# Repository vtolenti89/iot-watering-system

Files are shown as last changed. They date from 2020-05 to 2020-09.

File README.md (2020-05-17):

# IoT Watering System
Automated low power watering system 

# Overview
This project aims to automate a watering system for a small garden.
Due to the lack of an outside spigot / outdoor faucet, a large 
reservoir and an intermediate container were used to store the water,
which then was pumped to the plants at a regular interval using
an arduino controlled pump.  

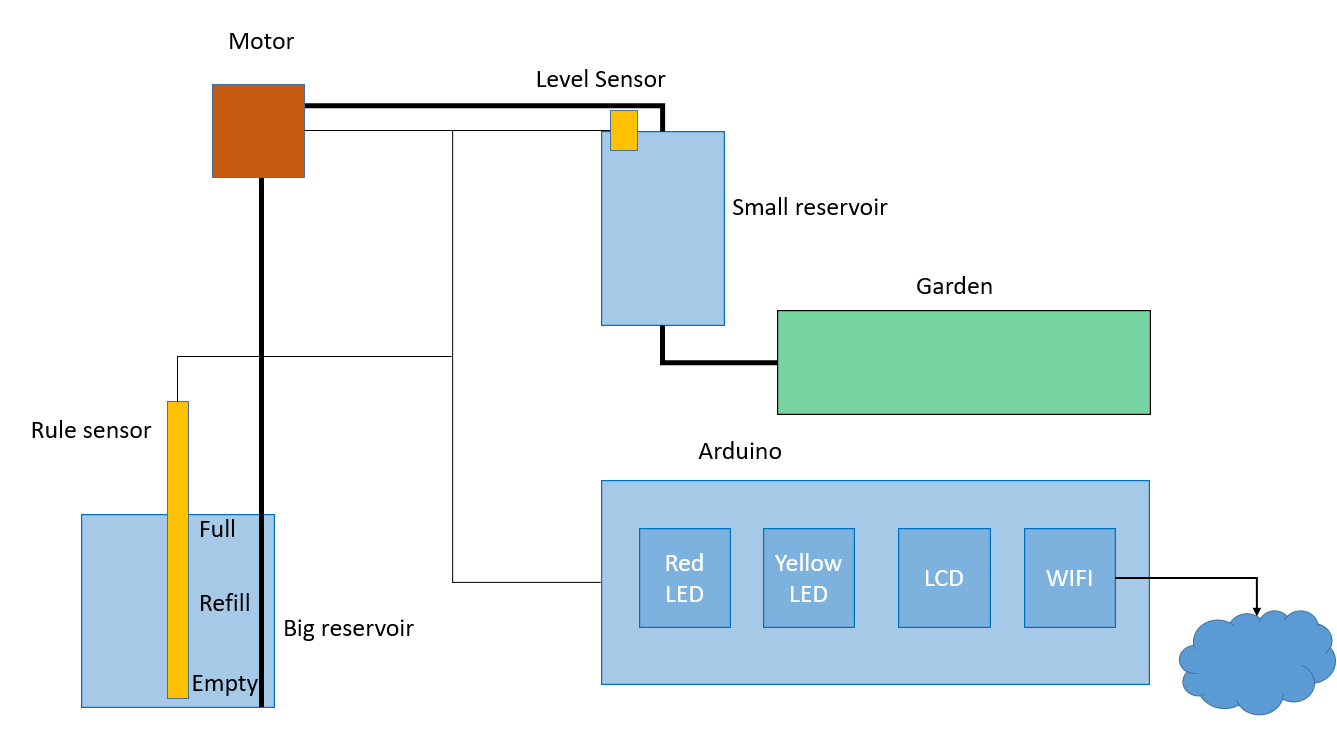
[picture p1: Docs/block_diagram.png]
Block diagram


# Description
The larger reservoir ensures that there is enough water for a resonable time.
Pumping the water to an intermediate container, alleviates the requirement
for the water pump, since it does not have to force the water through the end
nozzles. In this arrangement, gravity will ensure that the water is evenly 
distributed through all of them.
A homemade ruler sensor is used to measure the water level of the main tank,
while the smaller container's sensor prevents any overflow. 

# TODO
* Implement the display
* Implement again wifi with low power option

# History
* Implement a second code version, where the wifi is disabled and the power consumption is drastically
reduced by hardware modification and use of deep sleep routines
* Implement first version with wifi

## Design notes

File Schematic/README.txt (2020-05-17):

Several features of the current schematic were removed / disabled in order to improve the power consumption
Changes implemented in the arduino:

1. LDO removed, thus external supply voltage other than the USB is not possible
2. Apart from the built-in LED, all other LEDs were removed.
3. Supply voltage of the CH340 was removed

Changes implemented in the peripheral circuitry:

1. ESP8266 WIfi module removed
2. Water level meter disabled

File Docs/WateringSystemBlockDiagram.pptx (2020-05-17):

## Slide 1

Motor

Level Sensor

Small reservoir

Garden

Rule sensor

Arduino

Full

Red
LED

Yellow
LED

LCD

WIFI

Refill

Empty

Big reservoir

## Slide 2

Reservoir:
- Make sure pipe is in the bottom below the Empty sensor
Ruler Sensor:
- Full -> indicate in the LCD, RSV2 is full
- Refill -> indicate in the LCD to refill RSV2 (yellow LED blink slowly)
- Empty -> indicate in the LCD refill urgent (red LED blink fast), block the motor

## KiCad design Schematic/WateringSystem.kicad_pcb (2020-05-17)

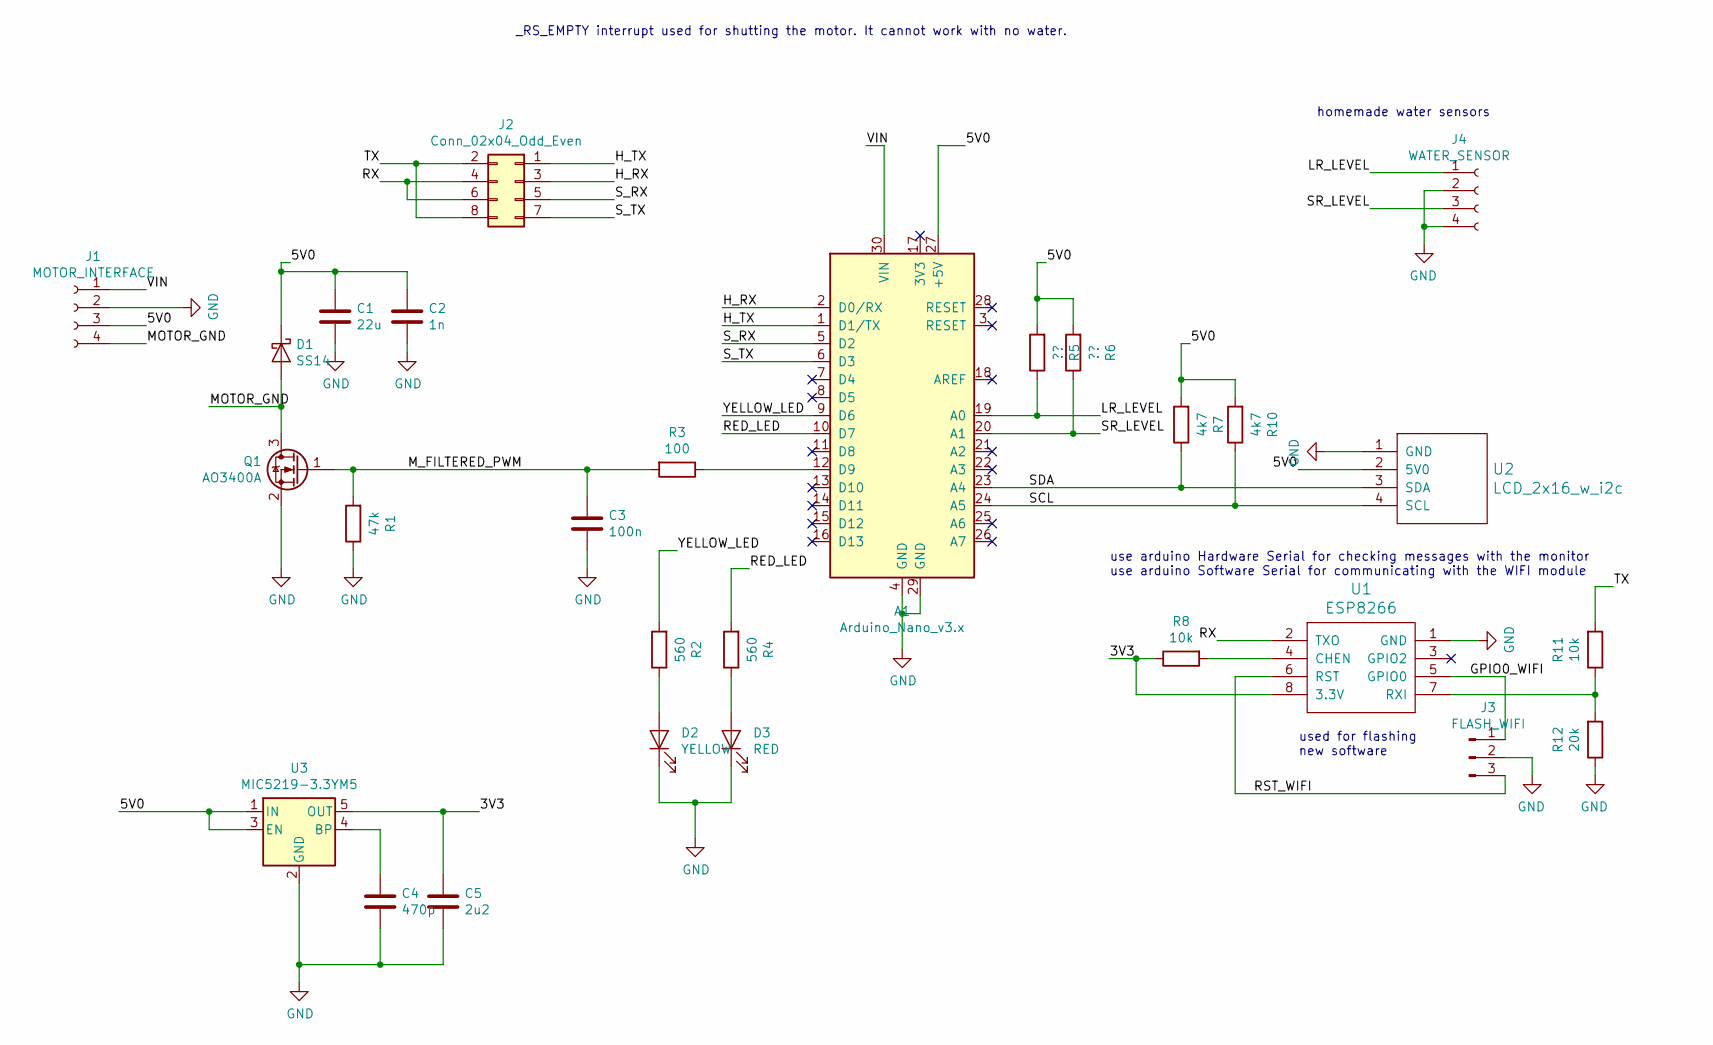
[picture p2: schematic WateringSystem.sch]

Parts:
A1: Arduino_Nano_v3.x; Arduino_Nano_WithMountingHoles
C1: 22u; C_0603_1608Metric_Pad1.05x0.95mm_HandSolder
C2: 1n; C_0603_1608Metric_Pad1.05x0.95mm_HandSolder
C3: 100n; C_0603_1608Metric_Pad1.05x0.95mm_HandSolder
C4: 470p; C_0603_1608Metric_Pad1.05x0.95mm_HandSolder
C5: 2u2; C_0603_1608Metric_Pad1.05x0.95mm_HandSolder
D1: SS14; SMA_DO-214AC
D2: YELLOW; LED_1206_3216Metric_Pad1.42x1.75mm_HandSolder
D3: RED; LED_1206_3216Metric_Pad1.42x1.75mm_HandSolder
J1: MOTOR_INTERFACE; PinHeader_1x04_P2.54mm_Vertical
J2: Conn_02x04_Odd_Even; PinHeader_2x04_P2.54mm_Vertical
J3: FLASH_WIFI; PinHeader_1x03_P2.54mm_Vertical
J4: WATER_SENSOR; PinHeader_1x04_P2.54mm_Vertical
Q1: AO3400A; SOT-23
R1: 47k; R_0603_1608Metric_Pad1.05x0.95mm_HandSolder
R2, R4: 560; R_0603_1608Metric_Pad1.05x0.95mm_HandSolder
R3: 100; R_0603_1608Metric_Pad1.05x0.95mm_HandSolder
R5, R6: ??; R_0603_1608Metric_Pad1.05x0.95mm_HandSolder
R7, R10: 4k7; R_0603_1608Metric_Pad1.05x0.95mm_HandSolder
R8, R11: 10k; R_0603_1608Metric_Pad1.05x0.95mm_HandSolder
R12: 20k; R_0603_1608Metric_Pad1.05x0.95mm_HandSolder
U1: ESP8266; PinHeader_2x04_P2.54mm_Vertical
U2: LCD_2x16_w_i2c; PinHeader_1x04_P2.54mm_Vertical
U3: MIC5219-3.3YM5; SOT-23-5

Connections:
/3V3: C5.1, R8.1, U1.8 (3.3V), U3.5 (OUT)
/5V0: A1.27 (+5V), C1.1, C2.1, D1.1 (K), J1.3, R5.2, R6.2, R7.2, R10.2, U2.2 (5V0), U3.1 (IN), U3.3 (EN)
/GPIO0_WIFI: J3.1, U1.5 (GPIO0)
/H_RX: A1.2 (D0/RX), J2.3
/H_TX: A1.1 (D1/TX), J2.1
/LR_LEVEL: A1.19 (A0), J4.1, R5.1
/MOTOR_GND: D1.2 (A), J1.4, Q1.3 (D)
/M_FILTERED_PWM: C3.1, Q1.1 (G), R1.2, R3.2
/RED_LED: A1.10 (D7), R4.2
/RST_WIFI: J3.3, U1.6 (RST)
/RX: J2.4, J2.6, U1.2 (TXO)
/SCL: A1.24 (A5), R10.1, U2.4 (SCL)
/SDA: A1.23 (A4), R7.1, U2.3 (SDA)
/SR_LEVEL: A1.20 (A1), J4.3, R6.1
/S_RX: A1.5 (D2), J2.5
/S_TX: A1.6 (D3), J2.7
/TX: J2.2, J2.8, R11.2
/VIN: A1.30 (VIN), J1.1
/YELLOW_LED: A1.9 (D6), R2.2
GND: A1.4 (GND), A1.29 (GND), C1.2, C2.2, C3.2, C4.2, C5.2, D2.1 (K), D3.1 (K), J1.2, J3.2, J4.2, J4.4, Q1.2 (S), R1.1, R12.1, U1.1 (GND), U2.1 (GND), U3.2 (GND)
unnamed: A1.12 (D9), R3.1
unnamed: C4.1, U3.4 (BP)
unnamed: D2.2 (A), R2.1
unnamed: D3.2 (A), R4.1
unnamed: R8.2, U1.4 (CHEN)
unnamed: R11.1, R12.2, U1.7 (RXI)

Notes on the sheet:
use arduino Hardware Serial for checking messages with the monitor use arduino Software Serial for communicating with the WIFI module
_RS_EMPTY interrupt used for shutting the motor. It cannot work with no water.
used for flashing new software
homemade water sensors

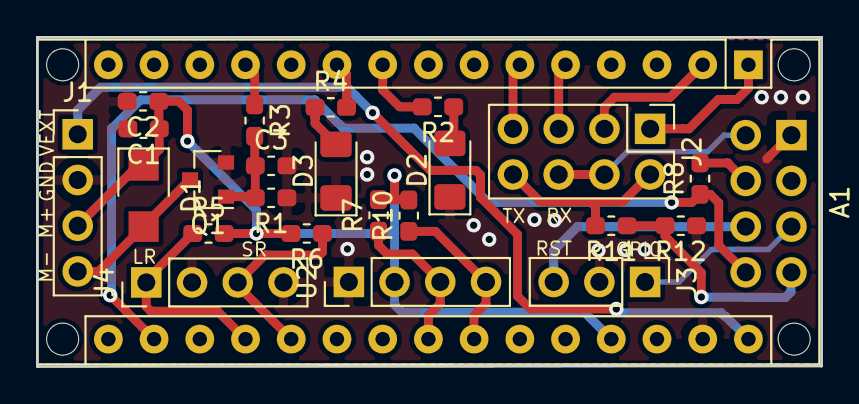
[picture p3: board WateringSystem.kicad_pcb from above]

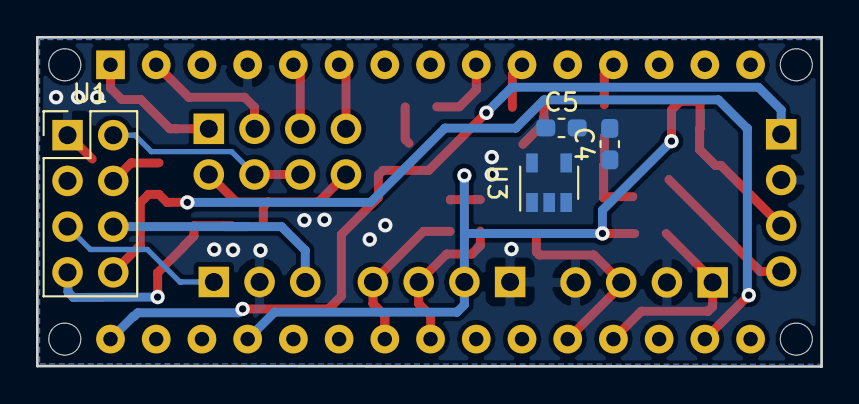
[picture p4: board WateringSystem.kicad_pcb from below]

Board: 2 copper layers, 43.6 x 18.3 mm, 28 parts (4 on the bottom side), 26 nets.

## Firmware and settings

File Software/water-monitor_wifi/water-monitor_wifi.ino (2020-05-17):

#include "helper.h"
#include "WiFiEsp.h"

enum waterLevelStates {
  WL_0 = 0, // water level is empty
  WL_20 = 20, // water level is 20%
  WL_40 = 40, // water level is 40% 
  WL_60 = 60, // water level is 60%
  WL_80 = 80, // water level is 80%
  WL_100= 100 // water level is 100%
};


// Emulate Serial1 on pins 6/7 if not present
#ifndef HAVE_HWSERIAL1
#include "SoftwareSerial.h"
SoftwareSerial Serial1(PD2, PD3); // RX, TX
#endif

//wifi settings
char ssid[] = "UPC6E2796A";            // your network SSID (name)
char pass[] = "Jmre8szre4ez";        // your network password
int status = WL_IDLE_STATUS;     // the Wifi radio's status

//router setting
const char url[] = "votolentino.com";
const long httpPort = 80; //default 80
const char epGetWaterLevel [] = "/garden";
const char epSetWaterLevel [] = "/garden/setwaterlevel/";
const char epUptHeartBeat [] = "/garden/updateheartbeat";
char epSetWaterLevelBuffer [sizeof(epSetWaterLevel) + 1]; 

//pin settings
const int yellowLed = PD6;
const int redLed = PD7;
const int motorPWM = PB1;
const int lWaterLevelPin = A0;
const int sWaterLevelPin = PC1;

//motor and water level settings
enum waterLevelStates wlState;
enum waterLevelStates previouswlState;
const long motorTurnOnDelay = 360; // minutes
const long motorOnTime = 20; //minutes 
long motorTimeDelay = 359; //minutes
long int lWaterLevel = 0
;

Helper helper;

// Initialize the Ethernet client object
WiFiEspClient client;

void setup()
{
    //Setting up pin inputs and outputs
  DDRD=0x00;
  DDRB=0x00;
  //DDRC=0x00;
  DDRD|=(1 << yellowLed) | (1 << redLed);
  DDRB|=(1 << motorPWM);
  //DDRC&=~((1 << lWaterLevelPin) | (1 << sWaterLevelPin));
  
  // initialize serial for debugging
  Serial.begin(115200);
  // initialize serial for ESP module
  Serial1.begin(9600);
  // initialize ESP module
  WiFi.init(&Serial1);

  // check for the presence of the shield
  if (WiFi.status() == WL_NO_SHIELD) {
    Serial.println("WiFi shield not present");
    // don't continue
    while (true);
  }

  // attempt to connect to WiFi network
  while ( status != WL_CONNECTED) {
    Serial.print("Attempting to connect to WPA SSID: ");
    Serial.println(ssid);
    // Connect to WPA/WPA2 network
    status = WiFi.begin(ssid, pass);
  }

  // you're connected now, so print out the data
  Serial.println("You're connected to the network");
  
  printWifiStatus();
  
  Serial.println();
  Serial.println("Starting connection to server...");
  // if you get a connection, report back via serial
  getReq(url, epUptHeartBeat);
}

void loop()
{
  // if there are incoming bytes available
  // from the server, read them and print them
  while (client.available()) {
    String c = client.readStringUntil('\n');
    Serial.println(c);
  }

  // if the server's disconnected, stop the client
  if (!client.connected()) {
    client.stop();
  }

    if(helper.getTimerFlag(2)){
      //PORTD^=(1 << yellowLed);
      //esp8266.getRequest(url , endpoint);
      
    }

   if(helper.getTimerFlag(3)){
    wlState = uptWaterState();
    //check water level
   }

   if(helper.getTimerFlag(4)){ 
    //only increment the motor time
    //if there is water in the tank
    if(wlState > WL_0) {
      motorTimeDelay++;      
    }

    getReq(url, epUptHeartBeat);
    Serial.print("motorTimeDelay:");
    Serial.println(motorTimeDelay);
    
   }

   if(motorTimeDelay >= motorTurnOnDelay && wlState > WL_0) {
      PORTB|=(1 << motorPWM);
      PORTD|=(1 << redLed);
      if(motorTimeDelay - motorTurnOnDelay > motorOnTime) {
        uptDBWaterLevel(wlState);
          Serial.println("Turning off the motor");
          PORTB&=~(1 << motorPWM);
          PORTD&=~(1 << redLed);
          motorTimeDelay=0;
        }
    }
    helper.updateTimer();
}


void getReq (char * url, char * endpoint) {
  // close any connection before send a new request
  // this will free the socket on the WiFi shield
  client.stop();
  
  if (client.connect(url, httpPort)) {
    Serial.println("Connecting...");
    // Make a HTTP request
    client.println("GET " + String(endpoint) +" HTTP/1.1");
    client.println("Host: " + String(url));
    client.println("Connection: close");
    client.println();
  }else {
    // if you couldn't make a connection
    Serial.println("Connection failed");
  }
}


void printWifiStatus()
{
  // print the SSID of the network you're attached to
  Serial.print("SSID: ");
  Serial.println(WiFi.SSID());

  // print your WiFi shield's IP address
  IPAddress ip = WiFi.localIP();
  Serial.print("IP Address: ");
  Serial.println(ip);

  // print the received signal strength
  long rssi = WiFi.RSSI();
  Serial.print("Signal strength (RSSI):");
  Serial.print(rssi);
  Serial.println(" dBm");
}


waterLevelStates uptWaterState() {
    lWaterLevel = analogRead(lWaterLevelPin);
    Serial.print("Water Level:");
    Serial.print(lWaterLevel);
    Serial.print(",WLState:");
    Serial.println(wlState);
    
  previouswlState = wlState;
  if(lWaterLevel >= 900) {
    return WL_0;
    } else if (lWaterLevel >= 800){
      return WL_20;
      }else if (lWaterLevel >= 650){
      return WL_40;
      }else if (lWaterLevel >= 600){
      return WL_60;
      }else if (lWaterLevel >= 500){
      return WL_80;
      } else {
        return WL_100;
        }
  //update the database if the wlState changed
  //if(previouswlState != wlState) {
      
  //}
}


void uptDBWaterLevel(int waterLevel) {
  sprintf(epSetWaterLevelBuffer, "%s%i", epSetWaterLevel, waterLevel);
  Serial.print("Setting Water level - Calling:");
  Serial.println(epSetWaterLevelBuffer);
  getReq(url, epSetWaterLevelBuffer);
}

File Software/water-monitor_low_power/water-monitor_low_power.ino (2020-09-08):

#include <avr/sleep.h>
#include <avr/wdt.h>

unsigned long previousMillis, secondCounter, currentMillis = 0;
const long interval = 1000;
const unsigned long watchdogInterval = 60 * 60 * 24 / 8; // called every 8 seconds -> 60 * 60 * 24 = 24 hours;
unsigned long watchdogCounter = watchdogInterval;
long int lWaterLevel = 0;
long unsigned motorCounter = 0;
const long motorOnTime = 20; // twenty minutes on

enum waterLevelStates {
  WL_0 = 0, // water level is empty
  WL_20 = 20, // water level is 20%
  WL_40 = 40, // water level is 40%
  WL_60 = 60, // water level is 60%
  WL_80 = 80, // water level is 80%
  WL_100 = 100 // water level is 100%
};

//pin settings
const int motorPWM = PB1;
const int lWaterLevelPin = A0;
const int sWaterLevelPin = PC1;

const int led = PB5;

//motor and water level settings
enum waterLevelStates wlState;
enum waterLevelStates previouswlState;



void setup()
{
  //Setting up pin inputs and outputs
  DDRD = 0x00;
  DDRB = 0x00;
  DDRB |= (1 << motorPWM);
  DDRB |= (1 << led);

  setupPowerSave();
  watchdogSetup();
}

void loop()
{
  //PORTB |= (1 << led);
  currentMillis = millis();

  if (currentMillis - previousMillis >= interval) {
    previousMillis = currentMillis;
    //  PORTB |= (1 << motorPWM);
    //PORTB |= (1 << led);

    //    motorCounter++;
    secondCounter++;
  }

  if (secondCounter >= 60) {
    secondCounter = 0;

    PORTB |= (1 << motorPWM);
    PORTB |= (1 << led);
    //watchdogCounter = 0;
    motorCounter++;
  }

  if (motorCounter > motorOnTime) {
    PORTB &= ~ (1 << motorPWM);
    PORTB &= ~ (1 << led);
    motorCounter = 0;
    watchdogCounter = 0;
  }

  if (watchdogCounter < watchdogInterval) {
    // Keep device sleeping
    previousMillis = currentMillis;
    PORTB &= ~ (1 << motorPWM);
    PORTB &= ~ (1 << led);
    motorCounter=0;
    secondCounter=0;
    enablePowerSave();
  }

}


void enablePowerSave() {
  cli();
  sleep_enable();
  sleep_bod_disable();
  sei();
  sleep_cpu(); // sleep now
  sleep_disable();
  /*
    MCUCR |= (3 << 5); // set both BOD5 and BODSE at the same time
    MCUCR = (MCUCR & ~ (1 << 5) | (1 << 6)); //then set the BODS bit and clear the BODSE bit at the same time
    asm("SLEEP");
  */
}

void watchdogSetup() {
  cli();
  wdt_reset();
  WDTCSR |= (1 << WDCE) | (1 << WDE); // change enable and WBE - also resets
  WDTCSR = (1 << WDIE) | (1 << WDP3) | (1 << WDP0); // 8s / interrupt, no system reset
  sei();
}

void setupPowerSave () {
  set_sleep_mode(SLEEP_MODE_PWR_DOWN);
  /*
    // Disable ADC
    ADCSRA &= ~(1 << 7);
    // Configure power down mode and enable it
    SMCR |= (1 << 2);
    SMCR |= (1 << 0);
  */
}

ISR(WDT_vect) { //put in additional code here
  watchdogCounter++;
}


waterLevelStates getWaterLevel() {
  lWaterLevel = analogRead(lWaterLevelPin);

  previouswlState = wlState;
  if (lWaterLevel >= 900) {
    return WL_0;
  } else if (lWaterLevel >= 800) {
    return WL_20;
  } else if (lWaterLevel >= 650) {
    return WL_40;
  } else if (lWaterLevel >= 600) {
    return WL_60;
  } else if (lWaterLevel >= 500) {
    return WL_80;
  } else {
    return WL_100;
  }
}
